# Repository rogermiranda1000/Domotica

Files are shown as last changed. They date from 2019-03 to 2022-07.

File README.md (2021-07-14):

# Domótica
Crea tu propia casa domótica mediante Arduino y Raspberry

## SETUP
- Necesitas poder [cargar código en la placa Lolin NodeMCU](https://www.instructables.com/Get-Started-With-ESP8266-NodeMCU-Lolin-V3/)
- Para la comunicación MQTT, arduino necesita [Libreria PubSubClient](https://pubsubclient.knolleary.net/)
- En la carpeta [libraries](https://github.com/rogermiranda1000/Domotica/tree/master/libraries) tienes las librerias que has de importar a Arduino

## Módulo botón
Envia una señal al pulsar el botón.
Para configurar su acción se ha de ir a Editar>Añadir botón, el nombre ha de ser su ID y el comando la acción que se desea realizar.

## Módulo seguridad
Detecta gases tóxicos para humanos. Avisa tanto por el buzzer, incluido en el módulo, como a la central.

## Módulo climático simple
Envia información sobre la temperatura, humedad y luz.
Para el uso en exteriores se recomienda el [Módulo climático avanzado](https://github.com/rogermiranda1000/Domotica#m%C3%B3dulo-clim%C3%A1tico-avanzado).

## Módulo climático avanzado
Envia información sobre la temperatura, humedad, nivel de agua y luz.

## Módulo estación meteorológica
Envia información sobre la temperatura, humedad, nivel de agua, luz, velocidad y dirección del viento.

Requerimientos:
- [Arduino UNO Wifi Rev2](https://store.arduino.cc/arduino-uno-wifi-rev2)
- [Sparkfun Weather Meter Kit](https://www.sparkfun.com/products/15901)
- [SparkFun Weather Shield](https://www.sparkfun.com/products/13956)
- [RJ11 Connector (x2)](https://www.sparkfun.com/products/132)

> **/!\\ Al soldar los pines del Shield no conecteis SDA ni SCL. /!\\**<br/>
> El Shield está creado para Arduino UNO, y la placa Arduino UNO Wifi Rev2 tiene un pinout de comunicación distinta. Además, [uno de los sensores tiene la misma ID de I2C que el chip de criptografia de la placa Rev2](https://forum.arduino.cc/t/arduino-uno-wifi-rev-2-and-liquidcrystal_i2c-solved/562494/18#msg4005531).<br/>
> El código se ha adaptado para usar los pines A4 y A5 como pines de I2C (mediante la libreria de SoftWire) para evitar los problemas mencionados.<br/>

> **/!\\ Si no usais Vin teneis que conectar Vin a +5V /!\\**<br/>
> El Shield está creado para Arduino UNO, y la placa [Arduino UNO Wifi Rev2 no suministra corriente a Vin si se alimenta mediante la toma de +5V](https://forum.arduino.cc/t/i2c-problem-while-using-sparkfun-weather-shield-on-arduino-uno-wifi-rev2/698082/33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).<br/>
> Un ejemplo de no usar Vin es cuando conectais la placa mediante USB.<br/>
> **Es importante que, si decidis usar Vin después de realizar la conexión, la quiteis o destruireis la placa.**

## Módulo alarma
Activa/desactiva la alarma. Se puede realizar mediante el keypad o el sensor dactilar.

## Módulo movimiento
Detecta el movimiento de la zona y avisa si detecta movimiento.

## Módulo apertura
Detecta aperturas de puertas y ventanas y avisa.

## Módulo enchufe
Da luz, o la bloquea en función de su estado.

## Módulo riego
Permite regar las plantas automáticamente.<br/>
Además de asignar la hora diaria de riego (o hacerlo manualmente), el programa central comprueba si hay altas probabilidades de lluvia al día siguiente y la humedad actual de las plantas para optimizar el agua.

## Módulo LED
Produce iluminación de distintos colores.

## Módulo central
El módulo central es el “cerebro” de todo el sistema domótico, además de realizar otras tareas.<br/>
Se compone de una parte que controla la comunicación (MQTT, mediante Python), otra responsable de la WEB (HTML, CSS, JavaScript y PHP), y otra de la base de datos (MariaDB).

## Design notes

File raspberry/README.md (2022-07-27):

# Módulo central
El módulo central es el “cerebro” de todo el sistema domótico, además de realizar otras tareas.<br/>
Se compone de una parte que controla la comunicación (MQTT, mediante Python), otra responsable de la WEB (HTML, CSS, JavaScript y PHP), y otra de la base de datos (MariaDB).

## SETUP
- Para la recepción de MQTT, el módulo central necesita [Mosquitto](https://mosquitto.org/blog/2013/01/mosquitto-debian-repository/). En '/etc/mosquitto/conf.d/mosquitto.conf' hay que indicarle la IP estática ('listener 1883 192.168.1.229' y 'allow_anonymous true').
- Se necesita MariaDB (el archivo a ejecutar para cargar la base de datos se encuentra en el [Módulo central](https://github.com/rogermiranda1000/Domotica#m%C3%B3dulo-central)). En su fichero de configuración hay que activar los schedulers (en linux, '/etc/mysql/my.cnf' y poner '[mariadb] event_scheduler=ON').
- El módulo central necesita una IP estática (busca como configurarlo dependiendo de su sistema)

## Ejecutar automáticamente el .py en Ubuntu
- Copiar 'mqtt_seguimiento_modulos.service' a la carpeta '/lib/systemd/system/'. Cambie la ruta de 'ExecStart' dependiendo de donde tenga el .py (para ver el directorio absouluto ejecutar 'pwd'), y el usuario 'User' donde se hayan instalado las librerias de Python.<br/>
- Ejecutar 'sudo systemctl enable mqtt_seguimiento_modulos.service'<br/>
- Ejecutar 'sudo systemctl start mqtt_seguimiento_modulos.service'

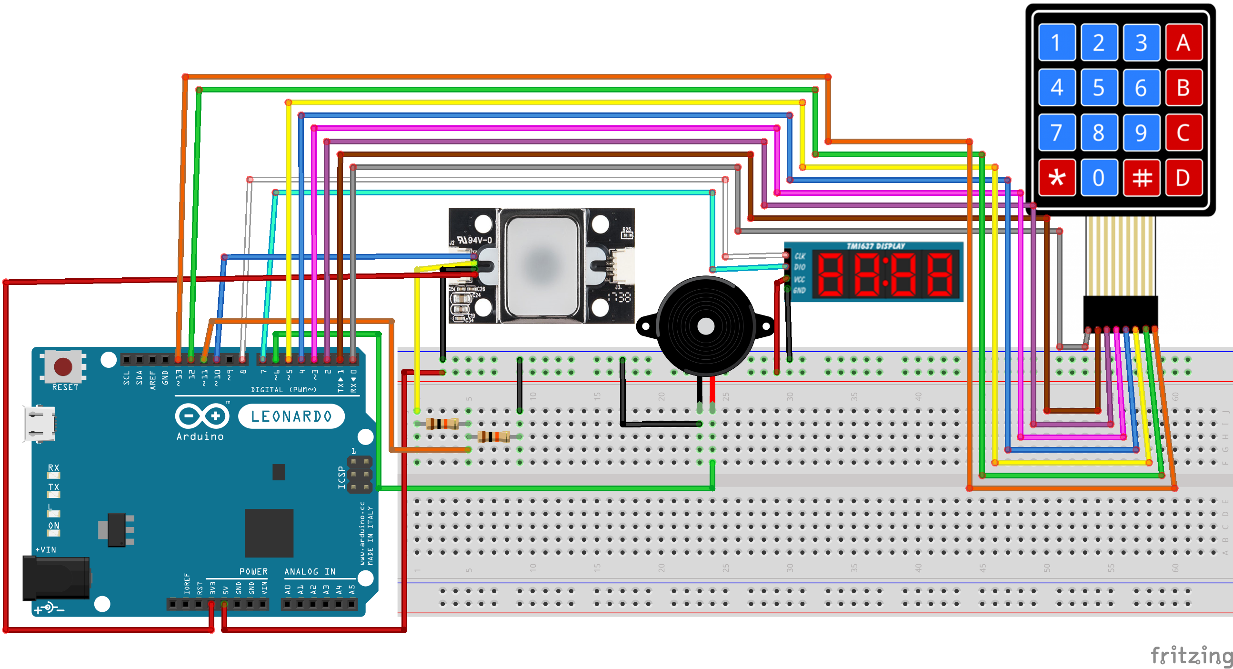
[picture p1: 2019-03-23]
alarma/diagrama.png

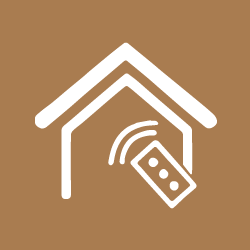
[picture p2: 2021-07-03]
raspberry/WEB/domotica-ico.png

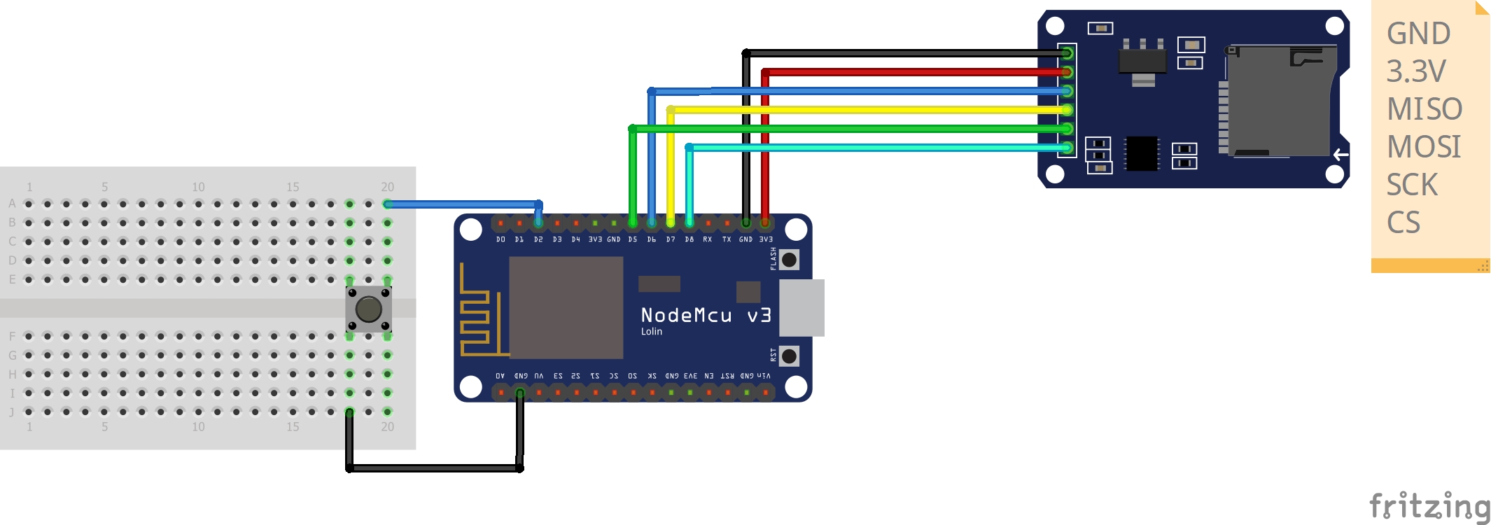
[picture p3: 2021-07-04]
boton/diagrama.jpg

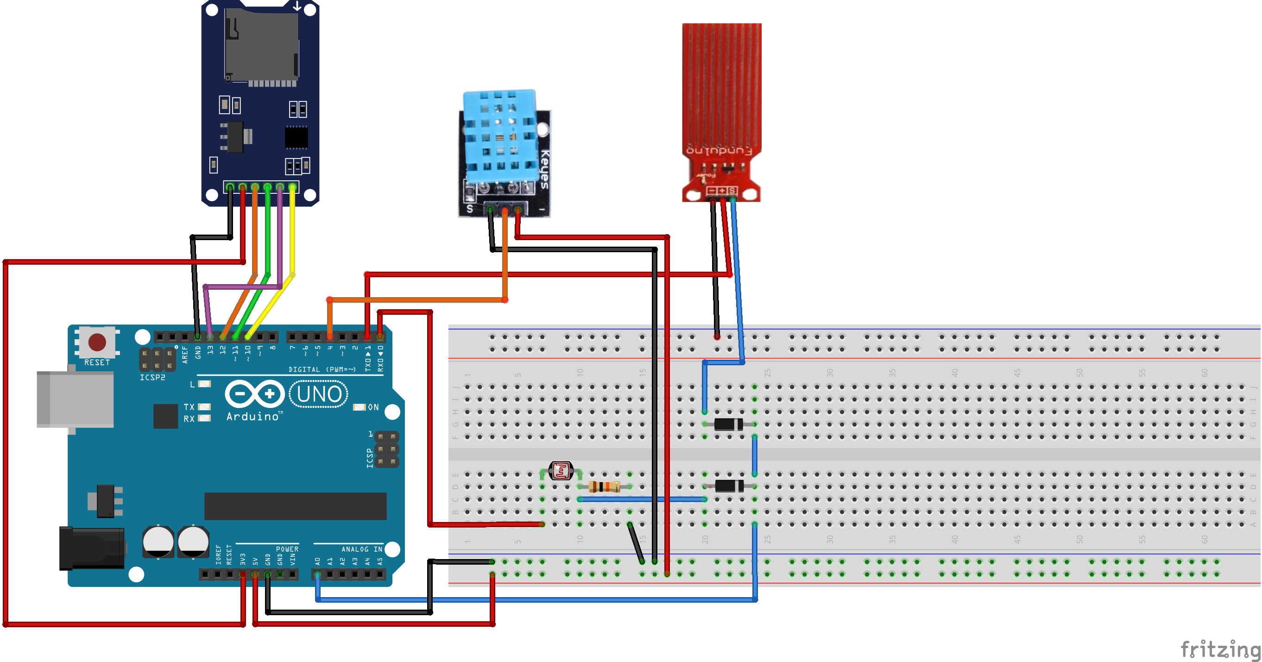
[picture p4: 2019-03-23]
climatico/avanzado/diagrama.png

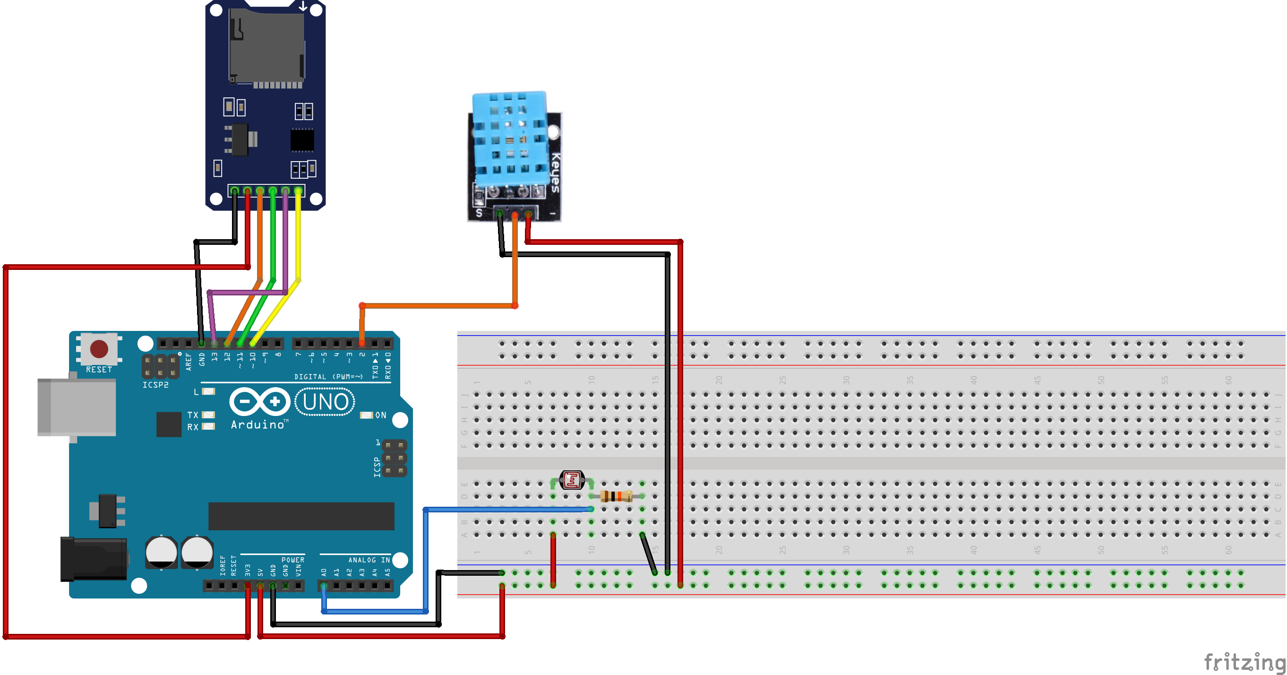
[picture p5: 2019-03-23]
climatico/simple/diagrama.png

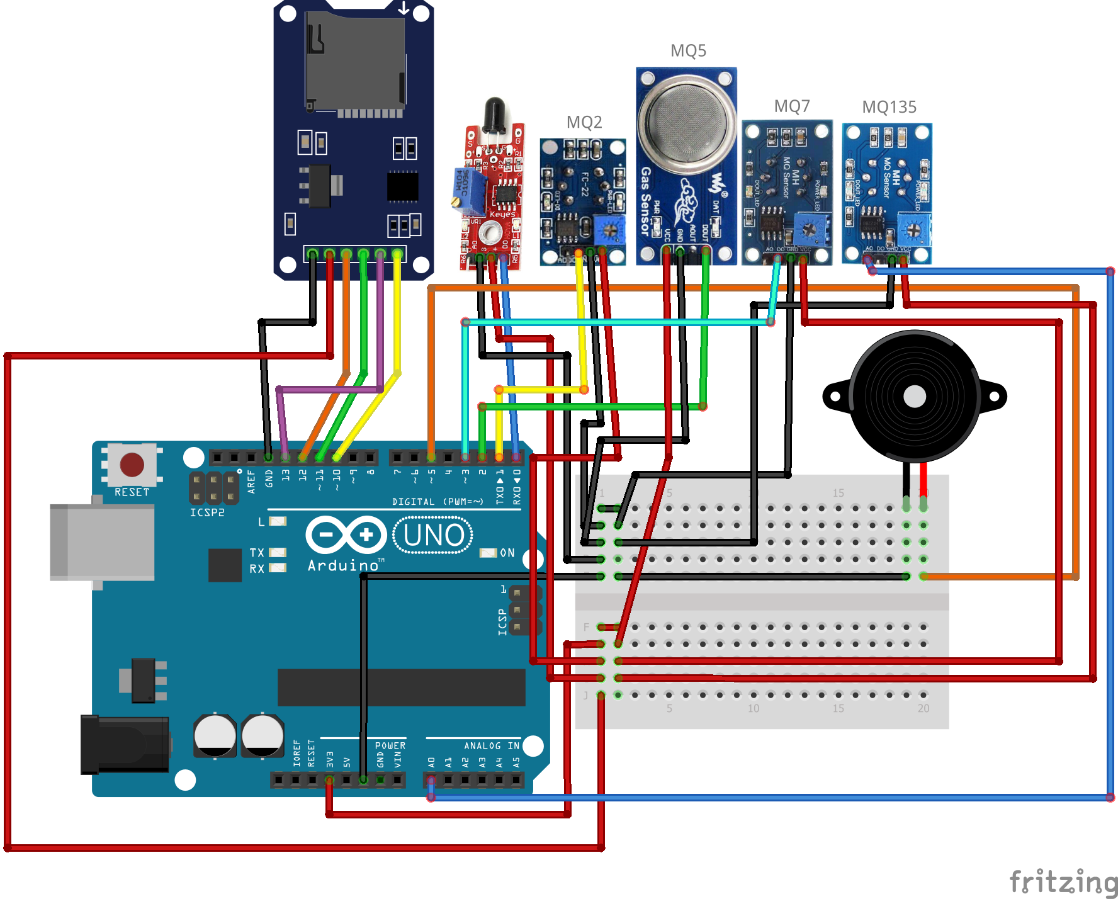
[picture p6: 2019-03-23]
seguridad/diagrama.png

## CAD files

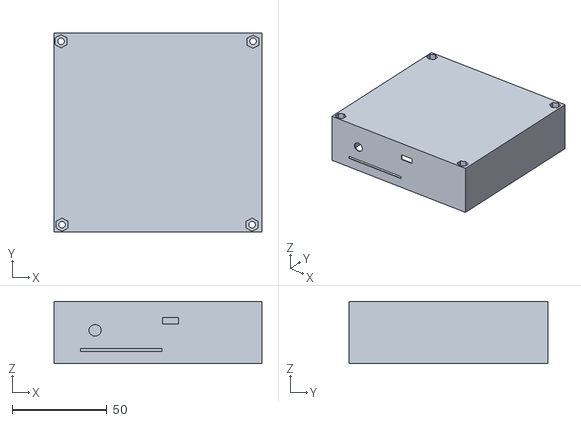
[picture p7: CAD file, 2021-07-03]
alarma/model-bottom.obj
110.0 x 105.0 x 33.0

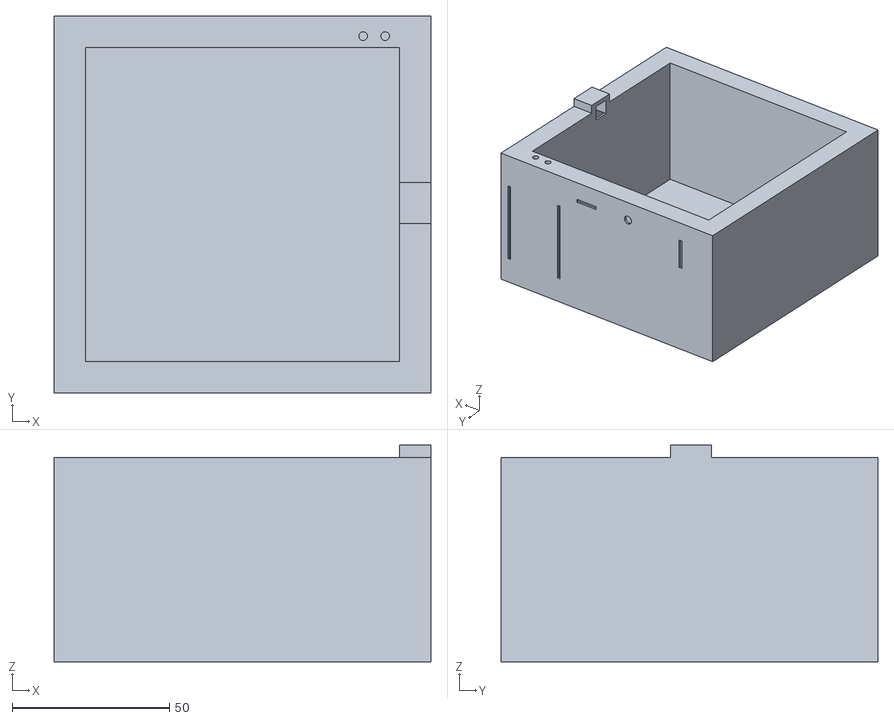
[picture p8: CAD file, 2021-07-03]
climatico/avanzado/model.obj
120.0 x 120.0 x 69.0

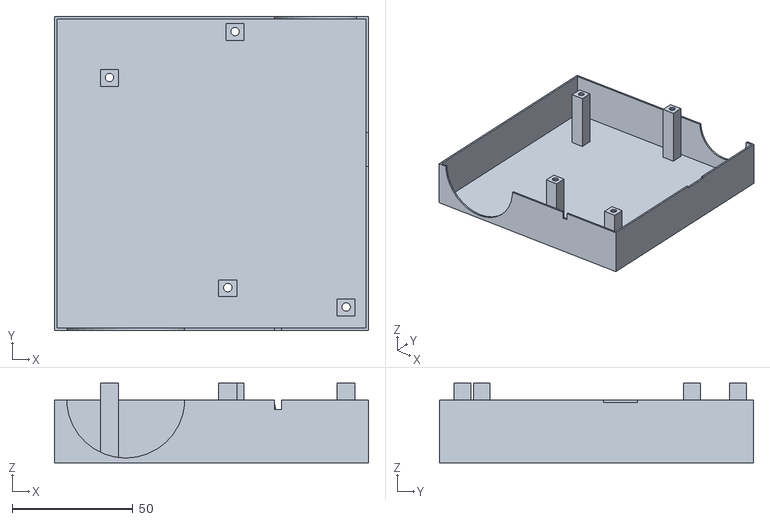
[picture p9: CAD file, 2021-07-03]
enchufe/model-top.obj
130.0 x 130.0 x 33.0

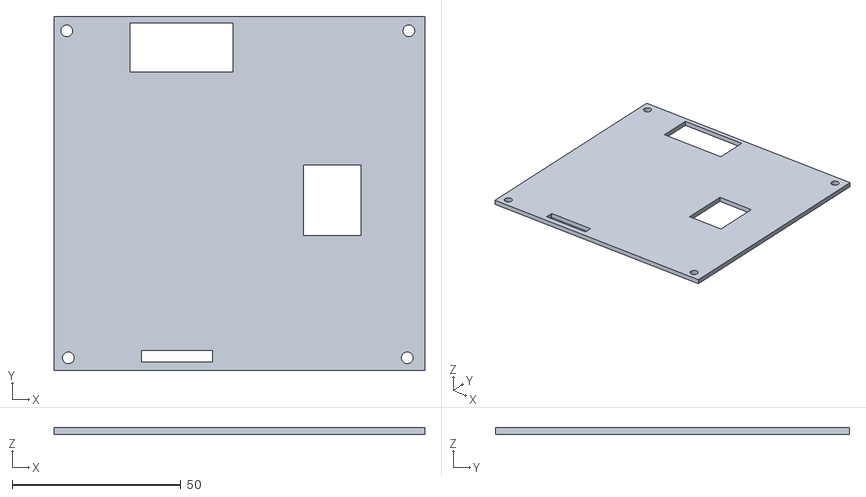
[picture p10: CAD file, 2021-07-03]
alarma/model-top.obj
110.0 x 105.0 x 2.00

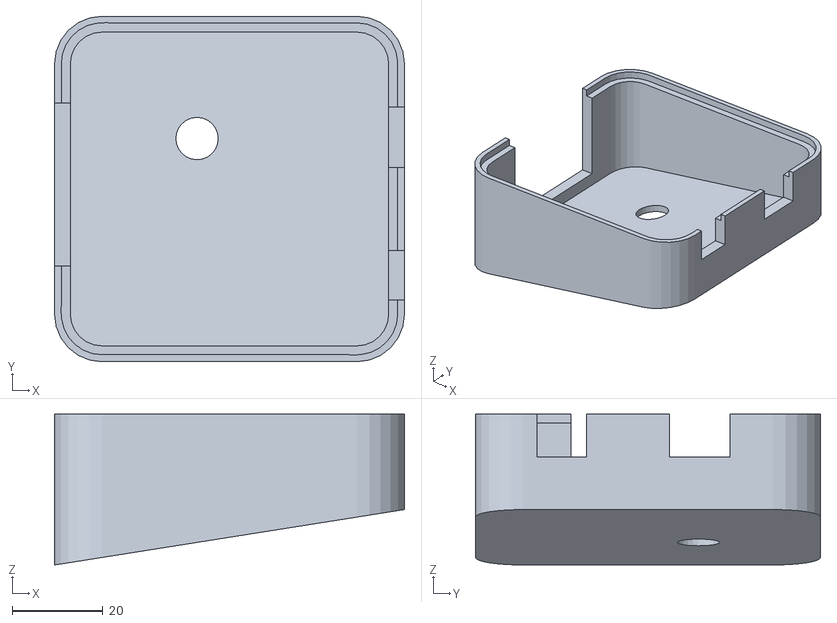
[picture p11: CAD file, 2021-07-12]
climatico/meteorologico/model-top.stl
77.3 x 76.3 x 33.3

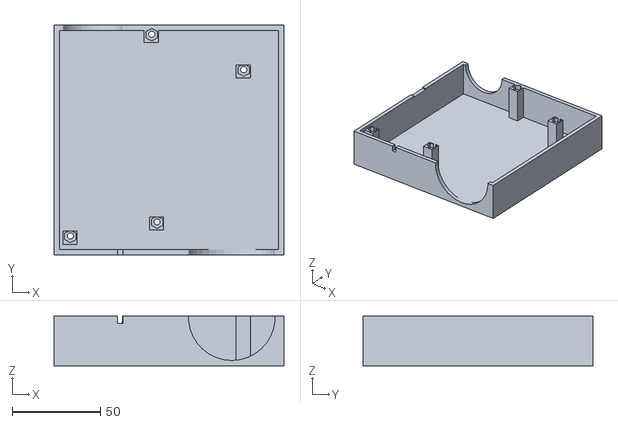
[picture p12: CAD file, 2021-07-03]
enchufe/model-bottom.obj
130.0 x 130.0 x 28.0

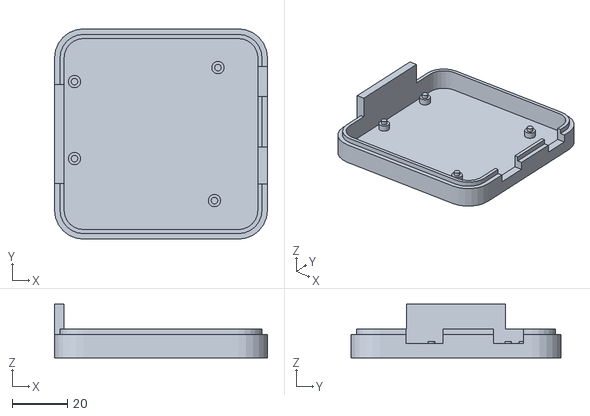
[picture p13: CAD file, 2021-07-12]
climatico/meteorologico/model-bottom.stl
77.3 x 76.3 x 19.5

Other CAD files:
climatico/meteorologico/model.dwg

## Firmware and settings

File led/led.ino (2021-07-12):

#include <DomoticConnector.h>

const char *const WIFI_NAME = NULL;//"...";
const char *const WIFI_PASS = NULL;//"...";

#define MQTT_SERVER "192.168.1.229"
#define MQTT_PORT   1883
#define GROUP       "led"

#define SD_PIN      D2
#define FILE_NAME   "credentials.txt"

#define WHITEPIN    D1
#define REDPIN      D3
#define GREENPIN    D8
#define BLUEPIN     D4

DomoticConnector *connector;
volatile bool anim = false;
uint8_t proceso = 0;
volatile int FADESPEED = 5; // make this higher to slow down

void turnOff(void) {
  analogWrite(WHITEPIN, 0);
  analogWrite(REDPIN, 0);
  analogWrite(GREENPIN, 0);
  analogWrite(BLUEPIN, 0);
}

void callback(char* topic, byte* payload, unsigned int length) {
  String mensaje = "";
  for (int i = 0; i < length; i++) mensaje += (char)payload[i];
  
  String msg[3] = {"", "", ""};
  int msg_val = 0;
  int pos;
  msg[0] = mensaje;
  while ((pos = mensaje.indexOf (' ')) != -1) {
    msg[msg_val] = mensaje.substring(0, pos);
    msg_val++;
    mensaje = mensaje.substring (pos + 1, mensaje.length());
  }
  msg[msg_val] = mensaje;
  Serial.println(msg[0] + "; " + msg[1] + "; " + msg[2]);
  
  if (msg[0] == "anim") {
    anim = true;
    proceso = 0;
  }
  else if (msg[0] == "animS") anim = false;
  else if (msg[0] == "off") {
    anim = false;
    turnOff();
  }
  else if (msg[0] == "on") {
    anim = false;
    analogWrite(WHITEPIN, 255);
    analogWrite(REDPIN, 255);
    analogWrite(GREENPIN, 255);
    analogWrite(BLUEPIN, 255);
  }
  else if (msg[0] == "delay") {
    FADESPEED = msg[1].toInt();
  }
  else if (msg[0] == "set") {
    anim = false;
    
    byte pin;
    if (msg[1] == "white") pin = WHITEPIN;
    else if (msg[1] == "red") pin = REDPIN;
    else if (msg[1] == "green") pin = GREENPIN;
    else if (msg[1] == "blue") pin = BLUEPIN;
    else return;
    
    analogWrite(pin, (unsigned byte)msg[2].toInt());
  }
}

void onReconnect(void) {
  connector->publish("central", connector->getStringID() + " led");
}

uint8_t c;
void executeAnimationM(byte pin) {
  analogWrite(pin, c);
  delay(FADESPEED);
  c++;
}

void executeAnimationL(byte pin) {
  analogWrite(pin, c);
  delay(FADESPEED);
  c--;
}

void setup() {
  Serial.begin(9600);
  
  Connector.setup(true, WIFI_NAME, WIFI_PASS, SD_PIN, FILE_NAME);
  connector = new DomoticConnector(MQTT_SERVER, MQTT_PORT, GROUP, onReconnect, ID_SUBSCRIPTION, callback);
  
  pinMode(WHITEPIN, OUTPUT);
  pinMode(REDPIN, OUTPUT);
  pinMode(GREENPIN, OUTPUT);
  pinMode(BLUEPIN, OUTPUT);
  
  turnOff();
}

void loop() {
  connector->loop();
  if (Serial.available()) Connector.eepromUpdate(Serial.readString());
  
  if (anim) {
    switch (proceso) {
      case 0:
        analogWrite(REDPIN, 0);
        analogWrite(GREENPIN, 0);
        analogWrite(BLUEPIN, 255);
        proceso++;
        break;
      
      case 1:
        c = 0;
        proceso++;
        break;

      case 2:
        executeAnimationM(REDPIN);
        if (c == 0) proceso++; // overflow (256 times done)
        break;
        
      case 3:
        c = 255;
        proceso++;
        break;

      case 4:
        executeAnimationL(BLUEPIN);
        if (c == 255) proceso++; // overflow (256 times done)
        break;
        
      case 5:
        c = 0;
        proceso++;
        break;

      case 6:
        executeAnimationM(GREENPIN);
        if (c == 0) proceso++; // overflow (256 times done)
        break;

      case 7:
        c = 255;
        proceso++;
        break;
        
      case 8:
        executeAnimationL(REDPIN);
        if (c == 255) proceso++; // overflow (256 times done)
        break;

      case 9:
        c = 0;
        proceso++;
        break;
        
      case 10:
        executeAnimationM(BLUEPIN);
        if (c == 0) proceso++; // overflow (256 times done)
        break;

      case 11:
        c = 255;
        proceso++;
        break;
        
      case 12:
        executeAnimationL(GREENPIN);
        if (c == 255) proceso = 0; // overflow (256 times done)
    }
  }
}

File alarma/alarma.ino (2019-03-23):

#include <Keypad.h>
#include "FPS_GT511C3.h"
#include "TM1637.h"

#include <ESP8266WiFi.h>
#include <PubSubClient.h>
#include <SD.h>String ssid = "";
String password = "";
char* mqtt_server = "192.168.1.230";
char* mqtt_server2 = "192.168.1.229";
bool dest = false;
WiFiClient espClient;
PubSubClient client(espClient);
File myFile;
char* ID = "ALAR01";

int pasado = 0;
bool activado = false;

const byte ROWS = 4;
const byte COLS = 4;
char hexaKeys[ROWS][COLS] = {
  {'1', '2', '3', 'A'},
  {'4', '5', '6', 'B'},
  {'7', '8', '9', 'C'},
  {'*', '0', '#', 'D'}
};
byte rowPins[ROWS] = {13, 12, 5, 4};
byte colPins[COLS] = {3, 2, 1, 0};
Keypad customKeypad = Keypad(makeKeymap(hexaKeys), rowPins, colPins, ROWS, COLS); 

FPS_GT511C3 fps(10, 11);

#define CLK 8
#define DIO 7
TM1637 tm1637(CLK,DIO);

const int buzzer = D6;

char password[4] = {' ', ' ', ' ', ' '};
bool alarma = false;
bool anadiendo = false;
//a = alarma; d = desactivar alarma; h = huella; m = añadir huella; n = añadir huella (password correcto)
char modo = ' ';
int tiempo = 0;

void setup(){
  Serial.begin(9600);
  //while(!Serial.available()) delay(1);
  
  fps.Open();
  
  tm1637.init();
  tm1637.set(BRIGHT_TYPICAL);
  
  pinMode(buzzer, OUTPUT);

  conectar();
}
  
void loop(){
  if (!client.connected()) reconnect();
  client.loop();

  if(activado) {
    pasado++;
    if(pasado%100<=50) tone(buzzer, 1000);
    else noTone(buzzer);
  }
  
  char customKey = customKeypad.getKey();
  
  if (customKey) {
    //Serial.println(customKey);
    if(customKey=='*') {
      reset();
      modo = 'h';
      fps.SetLED(true);
    }
    else if(customKey=='#') reset();
    else if(customKey=='A') {
      reset();
      modo = 'a';
      tiempo = 0;
      client.publish("central", (const char*) (String(ID) + " alarma act").c_str());
      for(int x = 0; x<4; x++) {
        tone(buzzer, 1000);
        delay(400);
        noTone(buzzer);
        delay(400);
      }
    }
    else if(customKey=='B') {
      reset();
      modo = 'd';
    }
    else if(customKey=='C');
    else if(customKey=='D') {
      reset();
      modo = 'm';
      fps.SetLED(true);
    }
    else {
      if(modo == 'd' || modo == 'm') {
        for(int x = 0; x!=3; x++) password[x] = password[x+1];
        password[3] = customKey;
        
        //Debug
        Serial.print("Password: ");
        String pass = "";
        for(int x = 0; x!=4; x++) {
          pass+=String(password[x]);
          tm1637.display(x,(int8_t) password[x]);
        }
        Serial.println(pass);

        if(password[x]!=' ') {
          String aci = "deact";
          if(modo=='m') aci = "enr";
          client.publish("central", (const char*) (String(ID) + " alarma "+aci+" "+pass).c_str());
        }
      }
    }
  }

  if(modo == 'a');
  else if(modo == 'h') {
    if (fps.IsPressFinger())
    {
      fps.CaptureFinger(false);
      int id = fps.Identify1_N();
      if (id <200) {
        //Huella válida
        client.publish("central", (const char*) (String(ID) + " alarma deact").c_str());
        modo = ' ';
      }
    }
  }
  else if(modo == 'n') {
    anadiendo = false;
    Enroll();
  }
}

void reset() {
  for(int x = 0; x!=4; x++) {
    password[x] = ' ';
    tm1637.display(x,' ');
  }
  if(modo=='m' || modo=='h') {
    fps.SetLED(false);
  }
}

void Enroll()
{
  if(anadiendo == true) return;
  anadiendo = true;
  // find open enroll id
  int enrollid = 0;
  bool usedid = true;
  while (usedid == true)
  {
    usedid = fps.CheckEnrolled(enrollid);
    if (usedid==true) enrollid++;
  }
  fps.EnrollStart(enrollid);

  // enroll
  Serial.print("Press finger to Enroll #");
  for(int x = 0; x!=4; x++) tm1637.display(x,(int8_t) 1);
  Serial.println(enrollid);
  while(fps.IsPressFinger() == false) delay(100);
  bool bret = fps.CaptureFinger(true);
  int iret = 0;
  if (bret != false)
  {
    Serial.println("Remove finger");
    for(int x = 0; x!=4; x++) tm1637.display(x,(int8_t) 0);
    fps.Enroll1(); 
    while(fps.IsPressFinger() == true) delay(100);
    Serial.println("Press same finger again");
    for(int x = 0; x!=4; x++) tm1637.display(x,(int8_t) 2);
    while(fps.IsPressFinger() == false) delay(100);
    bret = fps.CaptureFinger(true);
    if (bret != false)
    {
      Serial.println("Remove finger");
      for(int x = 0; x!=4; x++) tm1637.display(x,(int8_t) 0);
      fps.Enroll2();
      while(fps.IsPressFinger() == true) delay(100);
      Serial.println("Press same finger yet again");
      for(int x = 0; x!=4; x++) tm1637.display(x,(int8_t) 3);
      while(fps.IsPressFinger() == false) delay(100);
      bret = fps.CaptureFinger(true);
      if (bret != false)
      {
        Serial.println("Remove finger");
        for(int x = 0; x!=4; x++) tm1637.display(x,(int8_t) 0);
        iret = fps.Enroll3();
        if (iret == 0)
        {
          Serial.println("Enrolling Successful");
        }
        else
        {
          Serial.print("Enrolling Failed with error code:");
          Serial.println(iret);
          for(int x = 0; x!=4; x++) tm1637.display(x,(int8_t) 9);
        }
      }
      else Serial.println("Failed to capture third finger");
      for(int x = 0; x!=4; x++) tm1637.display(x,(int8_t) 9);
    }
    else Serial.println("Failed to capture second finger");
    for(int x = 0; x!=4; x++) tm1637.display(x,(int8_t) 9);
  }
  else Serial.println("Failed to capture first finger");
  for(int x = 0; x!=4; x++) tm1637.display(x,(int8_t) 9);
}

void activar() {
  activado = true;
}

void desactivar() {
  activado = false;
  for(int x = 0; x<3; x++) {
    tone(buzzer, 1000);
    delay(200);
    noTone(buzzer);
    delay(200);
  }
}

void callback(char* topic, byte* payload, unsigned int length) {
  String mensaje = "";
  for (int i=0;i<length;i++) mensaje += (char)payload[i];
  if(mensaje=="act") activar();
  else if(mensaje=="deact") desactivar();
  else if(mensaje=="enr") Enroll();
}
 
 
void reconnect() {
  while (!client.connected()) {
    Serial.print("Conectando...");
    if (client.connect(ID)) {
      Serial.println(" Conectado!");
      client.subscribe(ID);
      client.publish("central", (const char*) (String(ID) + " ?").c_str());
    } else {
      Serial.print("fallo, rc=");
      Serial.print(client.state());
      Serial.println(" intentado otra vez en 2 segundos...");
      cambiarDestino();
      delay(2000);
    }
  }
}

void cambiarDestino() {
  dest = !dest;
  if(dest) client.setServer(mqtt_server, 1883);
  else client.setServer(mqtt_server2, 1883);
}
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

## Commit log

2021-07-03 Fix: README; Added .obj 3d models
    [model-bottom.obj, model-top.obj, model.obj]
2021-07-03 Fix: fake press; Optimization: debug mode; Feature: ssid & password using #define; Fix: code blocked while holding button
    [boton.ino]
2021-07-03 Feature: more neat debug mode code; Diagram updated
    [diagrama.fzz]
2021-07-04 Fix: Button module not connecting to wifi
    [boton.ino]
2021-07-04 Fix: Button module sending action
    [boton.ino]
2021-07-04 README: Added button module instructions
2021-07-07 Library & Button module adapted
2021-07-07 Feature: Library colors; Fix: memory leak; Feature: multiple instances of DomoticConnector may be possible
    [boton.ino]
2021-07-08 LED module .ino
2021-07-08 Fix: EEPROM read overflow; Feature: LED module import DomoticConnector library
    [led.ino]
2021-07-08 Feature: cooperative loop; Fix: disable animation on setting LEDs to a certain color; Fix: digitalWrite after analogWrite generates undesired output
    [led.ino]
2021-07-08 communication.txt informando sobre el protocolo de comunicación de los módulos botón y LED
2021-07-09 Módulo apertura adaptado a la libreria
2021-07-09 Feature: instrucciones para el módulo estación meteorológica
2021-07-09 Fix: módulo apertura no comprobaba el canal serie
    [apertura.ino]
2021-07-09 Fix: protocolo del módulo apertura; Fix: modulo apertura cooperativo
    [apertura.ino]
2021-07-09 Fix: sending light in %
    [meteorologico.ino]
2021-07-09 Feature: optimized delay time; Fix: delay time in ms (now in seconds); Fix: rain sending NAN while not having battery connected
    [meteorologico.ino]
2021-07-09 Fix: rain sending NAN at the start
    [meteorologico.ino]
2021-07-10 Fix: Rain sensor
2021-07-10 Fix: WEB no mostraba correctamente los datos de los módulos
2021-07-11 Feature: meteorologic 3D case 1/2
    [model.dwg]
2021-07-11 Feature: meteorologic 3D case bottom (2d)
    [model.dwg]
2021-07-11 Feature: meteorologic 3D case bottom
    [model.dwg]
2021-07-12 Feature: re-made meteorologic 3D case bottom (2d)
    [model.dwg]
2021-07-12 Feature: un-made meteorologic 3D case bottom (2d)
    [model.dwg]
2021-07-12 Feature: meteorologic 3D case top (original heights)
    [model.dwg]
2021-07-12 Feature: meteorologic 3D case top (hole)
    [model.dwg]
2021-07-12 Feature: meteorologic 3D case top
    [model.dwg]
2021-07-12 Feature: meteorologic 3D case top (without top part)
    [model.dwg]
2021-07-12 Feature: re-try meteorologic 3D case top
    [model.dwg]
2021-07-12 Feature: meteorologic 3D case top (without light hole)
    [model.dwg]
2021-07-12 Feature: meteorologic 3D case
    [model-bottom.stl, model-top.stl, model.dwg]
2021-07-12 Fix: not finding IP; Feature: python modules install script
    [meteorologico.ino]
2021-07-12 Fix: non-cooperative delay; Feature: check if valid direction before sending
    [meteorologico.ino]
2021-07-12 Fix: pressure in Pa (not hPa)
    [meteorologico.ino]
2021-07-13 Fix: delay not changing
    [meteorologico.ino]
2021-07-13 Fix: timer overflow
2021-07-13 Fix: pressure not showing hPa
2021-07-13 Feature: temperature & humidity with Arduino BLE Sense
2021-07-13 Feature: pressure with Arduino BLE Sense
2021-07-13 Guess what... arduino BLE sense is only for BLE... :(
2021-07-14 Fix: insert modules using auto_increment
2021-07-22 Fix: DEBUG_PRINT on meteorologic module
    [meteorologico.ino]
